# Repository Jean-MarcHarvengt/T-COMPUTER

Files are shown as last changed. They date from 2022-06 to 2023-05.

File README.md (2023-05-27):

# What is the T-COMPUTER?
The T-COMPUTER is a micro computer platform supported and powered by the MCUME project.
- It is based on the powerful Teensy4.1 MCU (800+ MHz ARM based, 1MB internal + 8MB QSPI RAM)
- It features: 
  - a 42 keys basic keyboard (including D-PAD controls + 3 buttons)
  - a built-in 320x240 TFT display
  - VGA output 
  - 16 bits stereo DAC output
  - USB host input (for keyboard, mouse, midi devices...)
  - a DB9 digital joystick input (Atari 2600 style joystick)
  - 2 general purpose buttons    
  - 8+6 shared I/O pins for GP usage
  - a SD card slot (from the Teensy 4.1)
- it can be powered over micro USB or can be used as a takeaway system powered by a 1000mA/H lipo.   
- the T-COMPUTER is a DIY project, you can build it yourself and contribute to it!<br>

<p align="center">
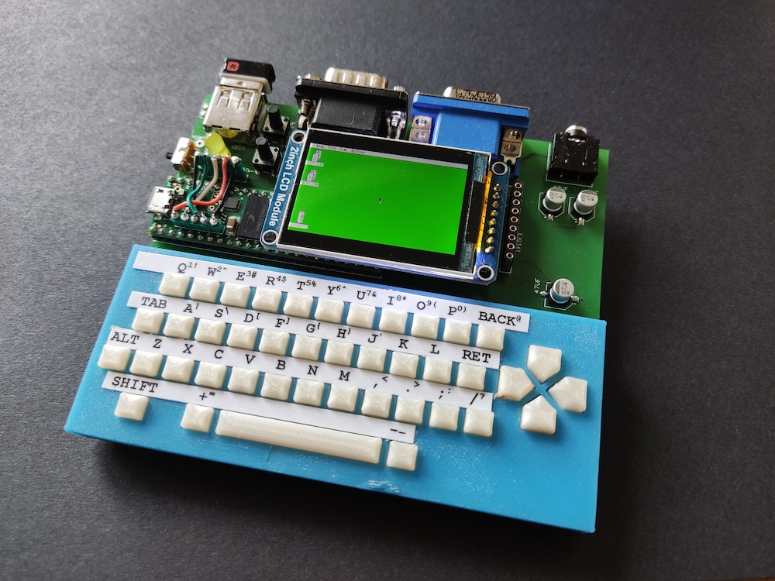
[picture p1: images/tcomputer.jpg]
  
</p>

T_COMPUTER running Super NES emulation and more...
https://youtu.be/K1JdkA93pqs <br>

# News

Mai 2023: Binaries updated<br>
- All binaries (except Doom) now support multiple displays (VGA,ST7789,ILI9341)
- Different binaries is no longer required. 
- Display is configured by means of a config file on the SD card.
- Read howto.txt for more details.
- SNES and MSX emulators have been also added.<br> 

June 2022: Initial release<br>
- After testing the Rev3 PCB from Aisler, I can finally release everything...
- Repository created with schematics, Gerber files, stl files and binaries
- How to build the T-COMPUTER (video in 3 parts)<br> 

https://youtu.be/jb_A_36Tv24 <br>
https://youtu.be/ADHyYO1vjXU <br>
https://youtu.be/OZnFfMv9jf4 <br>

# BOM

All the components needed are listed below.<br>
SMD resistors and ceramic capacitors are of type 805.<br>

<p align="left">
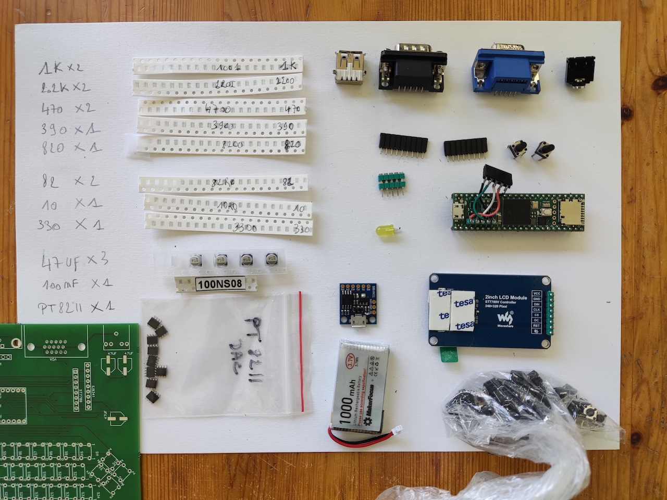
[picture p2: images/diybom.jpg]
  
</p>
<p align="left">
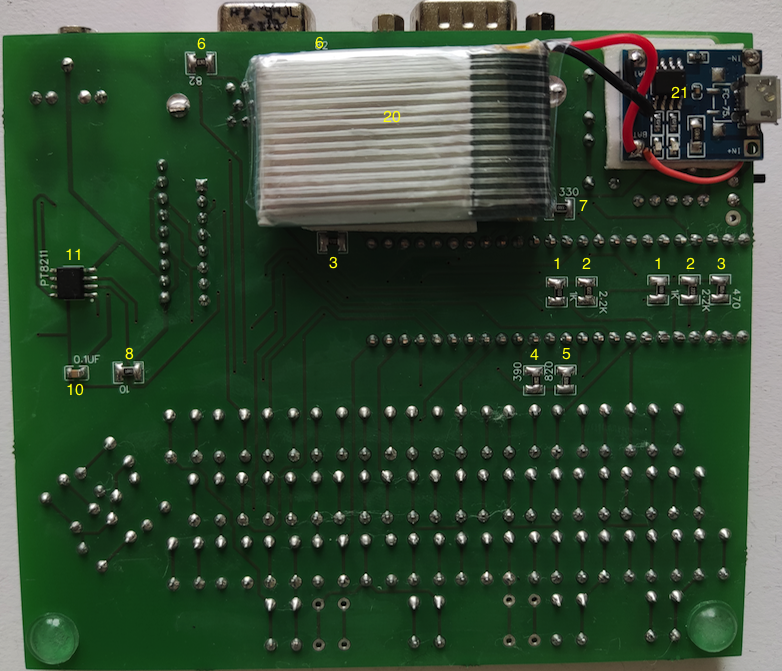
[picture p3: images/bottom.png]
  
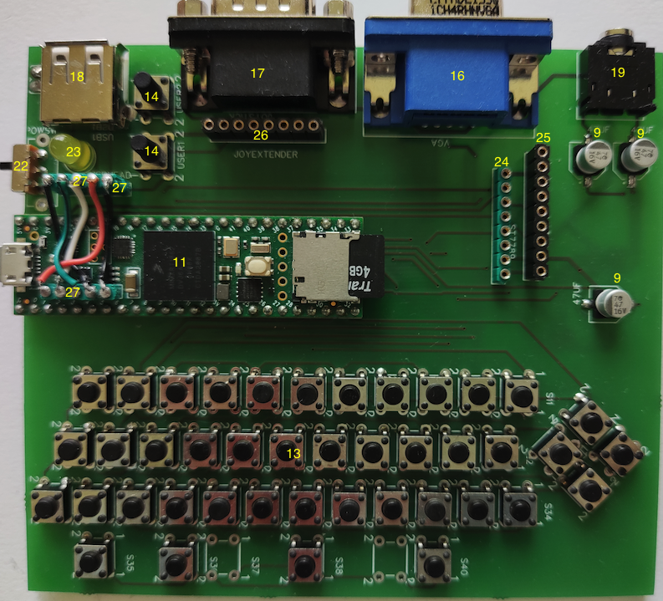
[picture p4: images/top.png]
  
</p>

<br>

| | Category | Item | Amount | Link |
| --- | --- | --- | --- | --- |
| 1 | resistors| 1KOhms | 2 | --- |
| 2 | | 2.2KOhms | 2 | --- |
| 3 | | 470Ohms | 2 | --- |
| 4 | | 390Ohms | 1 | --- |
| 5 | | 820Ohms | 1 | --- |
| 6 | | 82Ohms | 2 | --- |
| 7 | | 330Ohms | 1 | --- |
| 8 | | 10Ohms | 1 | --- |
| 9 | electolytic capa | 4.7uF | 3 | --- |
| 10| ceramic capa | 100nF | 1 | --- |
| 11| IC| Teensy4.1 | 1 | --- |
| 12| IC| PT8211 | 1 | --- |
| 13| switches| classic | 42 | --- |
| 14| switches| high | 2 | --- |
| 15| TFT| ST7789 | 1 | --- |
| 16| VGA| DB15 female | 1 | --- |
| 17| JOYSTICK| DB9 male | 1 | --- |
| 18| USB| ? | 1 | --- |
| 19| AUDIO| Jack female | 1 | --- |
| 20| Battery| lipo 1000mAh | 1 | --- |
| 21| USB micro lipo charger| pcb | 1 | --- |
| 22| power switch| 3 pins, mini | 1 | --- |
| 23| LED| green or yellow | 1 | --- |
| 24| ST7789 HEADER| 1x8 | 1 | --- |
| 25| ILI9341 HEADER| 1x9 | 1 | --- |
| 26| JOYEXT HEADER| 1x8 | 1 | --- |
| 27| USB HEADER| 1x5 | 3 | --- |

# Assembly
Location and values for the components are printed on the PCB.<br>
Respect the polarity for of electrolytic capacitors (dot indicates the +) and the IC (dot is pin 1).<br>
Follow the step procedure below and test between the steps:
- before starting anything, 
  -  solder the PSRAM chip on the teensy 4.1 board and test it
     - use the sketch provided by the PJRC project
  - solder the header pins of the teensy (classic male header pins), including the 1x5 usb header pins (I use female low profile personally)
  - after that, program the teensy with one of the VGA emulator in /bin
- step 1: VGA out + keys
  - solder all smd resistors
  - solder the 4 switches of the direction D-PAD at the right of the keyboard
  - solder the VGA connector
  - solder the Teensy 4.1 (use female header as socket, don't solder directly!!!)
  - power the teensy over micro usb and test
- step 2: sound out + keyboard
  - solder the PT8211 IC
  - solder all smd capacitors (respect polariry for the electrolytics)
  - solder all keys of the keyboard + the 2 user keys 
  - solder the audio jack female connector
  - power the teensy over micro usb and test
- step 3: USB + joystick
  - solder the joystick DB9 connector
  - solder the ST and ILI header pins (female pins)
  - solder the joyext header pins (female pins)
  - solder the USB connector + USB header pins on the PCB (2 times 5xfemales pins on top of each other)
  - connect the Teensy USB header pins to the PCB USB top header pins using wires
  - power the teensy over micro usb and test
- step 4: TFT display
  - connect the TFT display (e.g. st7789 2 inches)
  - program the teensy with one of the TFT emulator in /bin
  - power the teensy over micro usb and test
- step 5 (optional):  
  - solder the power switch
  - solder the battery to the USB charger PCB kit
  - glue the USB charger PCB kit at the back of the T-COMPUTER board and solder the power pins
  - glue the battery at the back of the T-COMPUTER board
  - Always DISCONNECT the teensy micro usbcable when powering up the system via the battery.
  - power switch down = battery powered

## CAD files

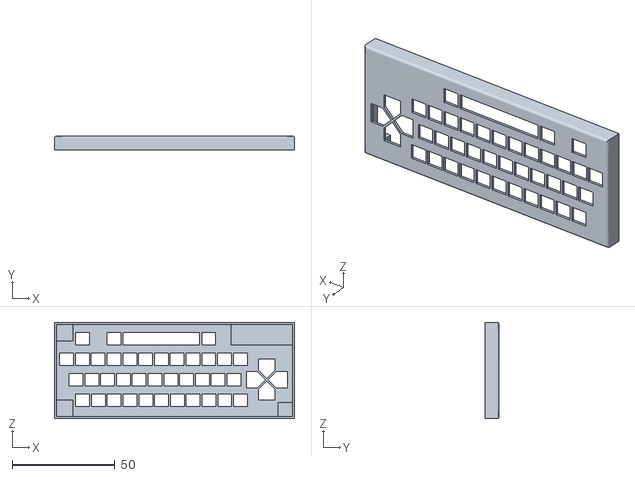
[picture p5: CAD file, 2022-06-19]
stl/t-computer_case.stl
117.0 x 7.00 x 47.0

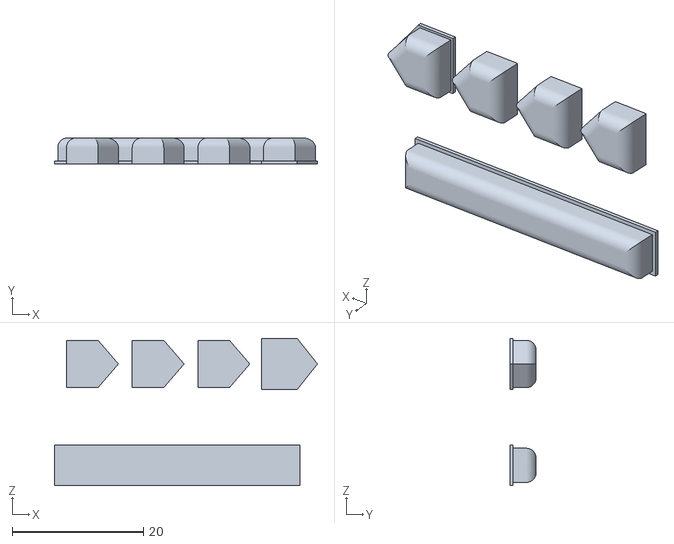
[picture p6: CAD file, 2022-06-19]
stl/t-computer_pad.stl
40.0 x 4.00 x 22.4

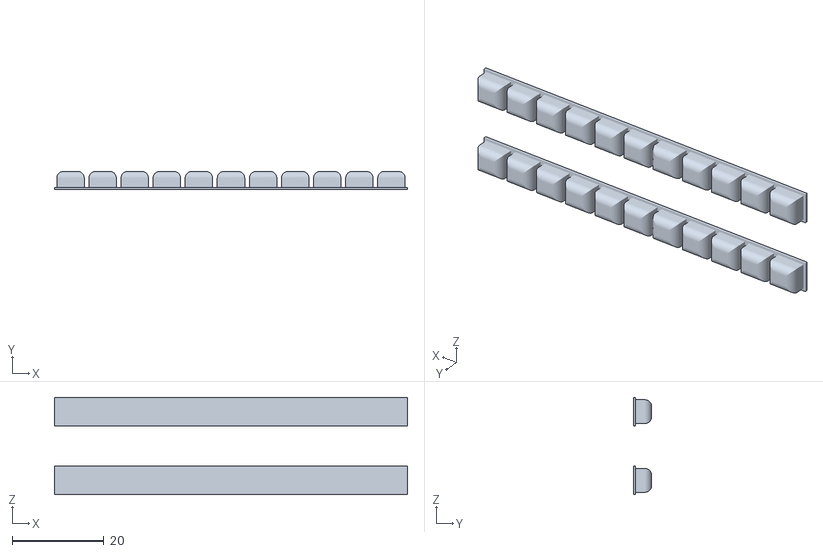
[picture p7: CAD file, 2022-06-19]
stl/t-computer_keys.stl
77.0 x 4.00 x 21.2

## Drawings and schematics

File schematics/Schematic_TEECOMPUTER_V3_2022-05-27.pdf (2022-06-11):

# ID3/SCL 15 ¹⁶ 17

## Teensy 4.0 & 4.1

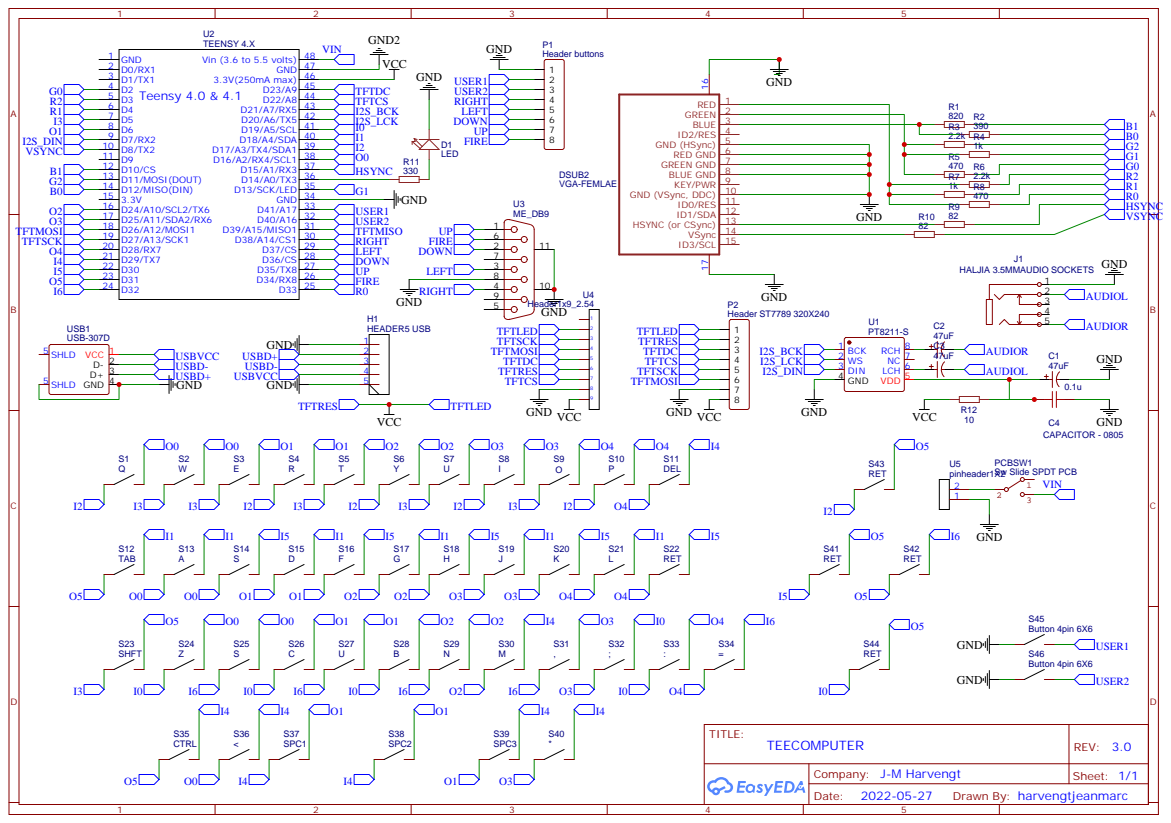
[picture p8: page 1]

PCBSW1
Sw Slide SPDT PCB

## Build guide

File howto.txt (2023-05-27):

Compile:
------- 
See MCUME Github project, howtocompile.txt in MCUME_teensy41 subdirectory

Controls:
--------
In file browser...
-Use up/down to select a file.
-Left/Right for paging.
-TCOMPUTER TAB/OK to start.
-TCOMPUTER ALT to start in VGA if was configured to display many on LCD.  
-TCOMPUTER ALT+SHIFT to reset.
Configure the display (persistent)
-Press Up while booting to force VGA output at startup (will erase config)
-Press Left while booting to force ST7789 output at startup (will write config)
-Press Right while booting to force ILI9341 output at startup (will write config)
Autorun:
-You can keep the TCOMPUTER shift key pressed when launching a game (with TAB). 
 It will AUTORUN the same game at following boot/reset. 
-Press Down while resetting/booting will erase/disable AUTORUN.
During emulation...
-ALT or SHIFT on TCOMPUTER for extra keyboard functions (typically digits + special chars)
-Keep ALT on for 3 secs for more keyboard functions (typically function keys on 1..10)
-Cursor control in text require pressing shift in computer emus. 
Atari/C64 like joystick can plugged to play or you can use up/dow/left/right keys + TAB/ALT/SHIFT
Some console emus have extra keys on USER1/USER2 keys or q,w,e...p 
C64 emu also uses ALT+BACK to load file the first time it is pressed.
ALT sometimes used to swap between mouse/joystick or joystick1/2 port.

You can use USB keyboard/mouse for most computer emus.
